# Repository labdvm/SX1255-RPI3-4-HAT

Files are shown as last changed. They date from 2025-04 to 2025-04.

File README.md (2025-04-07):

[][cc-by-nc-sa]

# SX1255_HAT-hw (schematic and pcb modified by Z32IT)
Raspberry Pi 3-4 shield with the SX1255 RF transceiver chip.

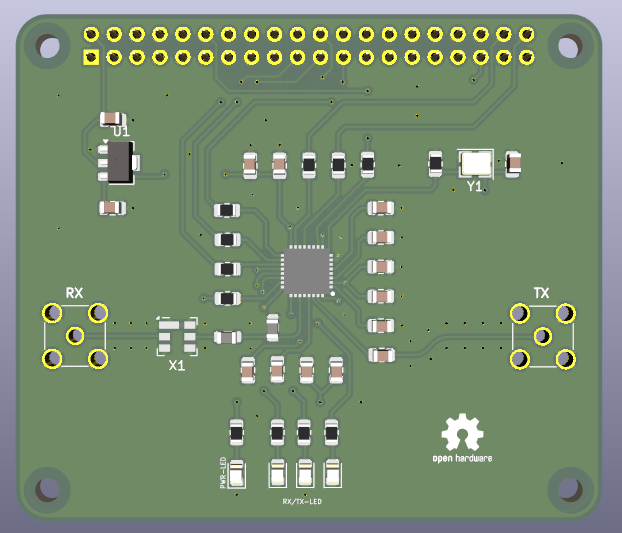
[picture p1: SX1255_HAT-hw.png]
Board preview


## Usage
### RPi sample config code
Sample Raspberry Pi code for SX1255 control can be found [here](https://gist.github.com/sp5wwp/25fa989ebd98b3b707eadae9b63af679).<br>
[I2S slave overlay](https://github.com/AkiyukiOkayasu/RaspberryPi_I2S_Slave) is required. Sample rate for both RX and TX is 125kHz.

RX/TX frequency setting:
```
./sx1255-spi 435000000 438000000
```

### Example RX with ZeroMQ
```
arecord -t raw -f S32_LE -r 192000 -c 2 --device="hw:0,1" | ./int_to_short | ./zmq-pub
```

In which `int_to_short` is a simple `int` to `short` format converter:
```C
while(1)
{
  ioctl(STDIN_FILENO, FIONREAD, &rcvd);
  if(rcvd>0)
  {
    if(read(STDIN_FILENO, inp, rcvd)==rcvd)
    {
      for(int i=0; i<rcvd; i+=8)
      {
        memcpy(&out[i/2  ], &inp[i  +2], 2);
        memcpy(&out[i/2+2], &inp[i+4+2], 2);
      }

      write(STDOUT_FILENO, out, rcvd/2);
    }
  }
}
```

### Example TX with ZeroMQ
```
./zmq-sub 192.168.50.243:17018 | aplay -t raw -f S32_LE -r 192000 -c 2 --device="hw:0,0"
```

## License
This work is licensed under a
[Creative Commons Attribution-NonCommercial-ShareAlike 4.0 International License][cc-by-nc-sa].

[][cc-by-nc-sa]

[cc-by-nc-sa]: http://creativecommons.org/licenses/by-nc-sa/4.0/
[cc-by-nc-sa-image]: https://licensebuttons.net/l/by-nc-sa/4.0/88x31.png
[cc-by-nc-sa-shield]: https://img.shields.io/badge/License-CC%20BY--NC--SA%204.0-lightgrey.svg

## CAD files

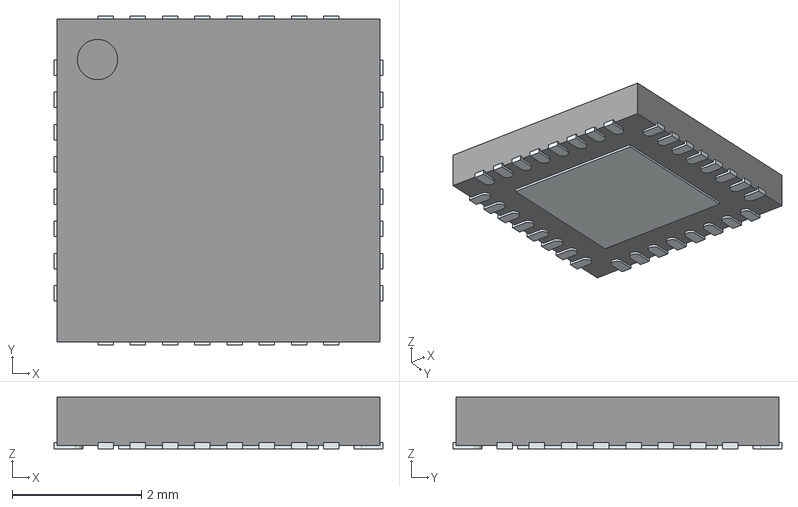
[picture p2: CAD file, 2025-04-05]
parts/SX1255IWLTRT.stp
5.10 x 5.10 x 0.8 mm
ThermalPin
PinsArrayLR
PinsArrayTB

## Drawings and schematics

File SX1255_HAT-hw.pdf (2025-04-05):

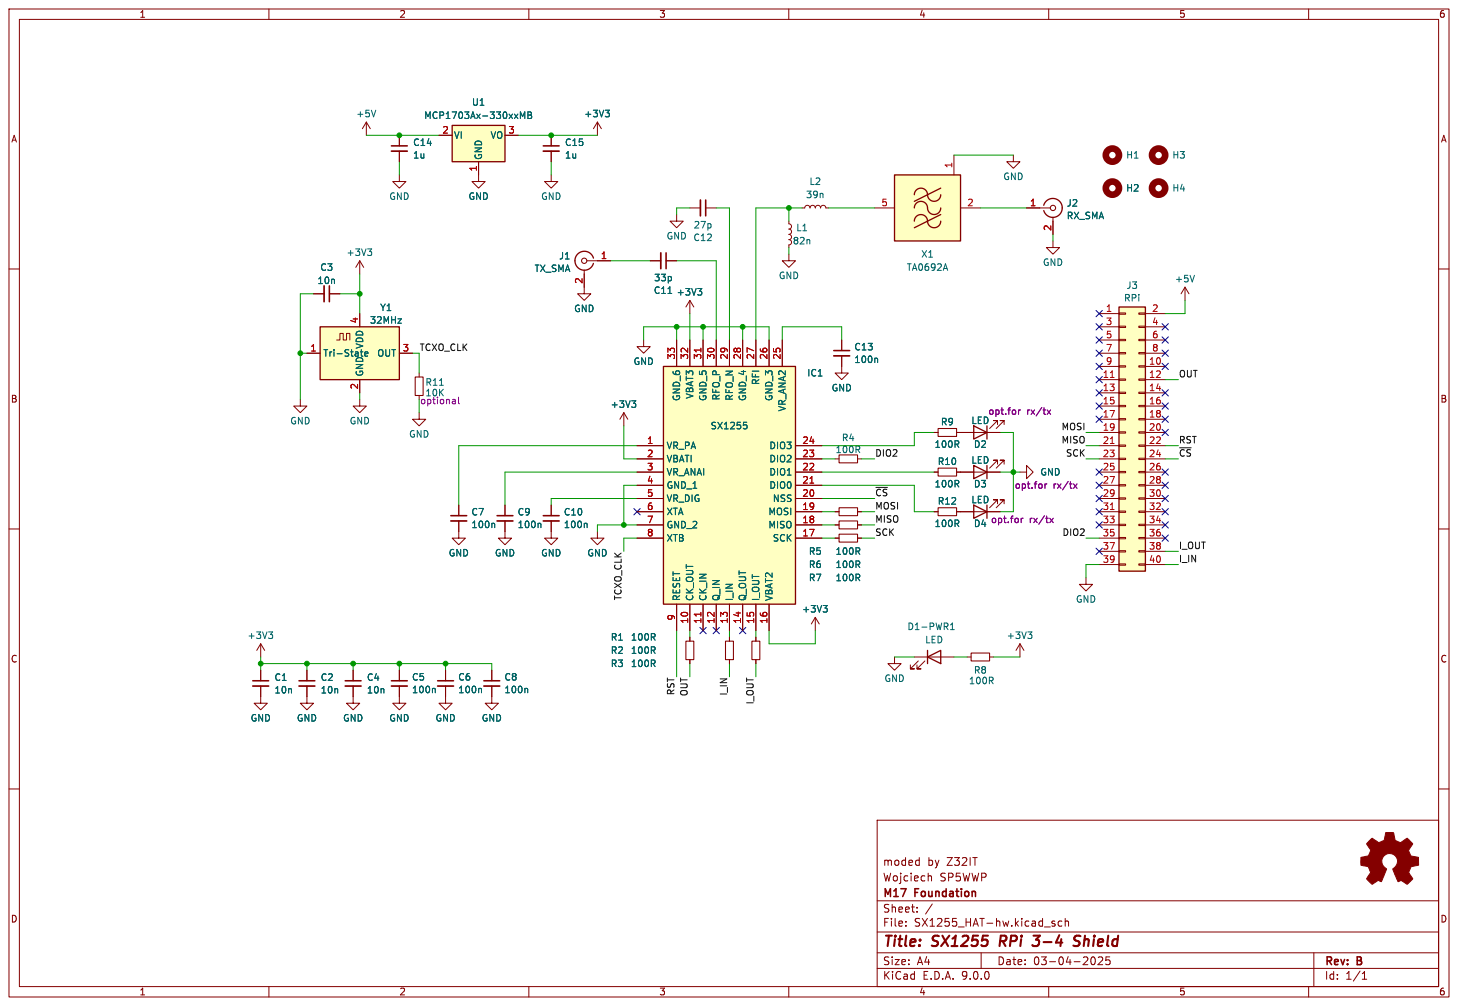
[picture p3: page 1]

27p GND
opt.for rx/tx C12

9 VBAT3 32 CK_OUT 10 GND_5 31 CK_IN 11 RFO_P 30 Q_IN 12 RFO_N 29 I_IN 13 GND_4 28 Q_OUT 14 RFI 27 I_OUT 15 GND_3 26 VBAT2 16 VR_ANA2 25 DIO3 24 DIO2 23 DIO1 22 DIO0 21 NSS 20 MOSI 19 MISO 18 SCK 17 GND

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

opt.for rx/tx R12

opt.for rx/tx D3
opt.for rx/tx D4
LED

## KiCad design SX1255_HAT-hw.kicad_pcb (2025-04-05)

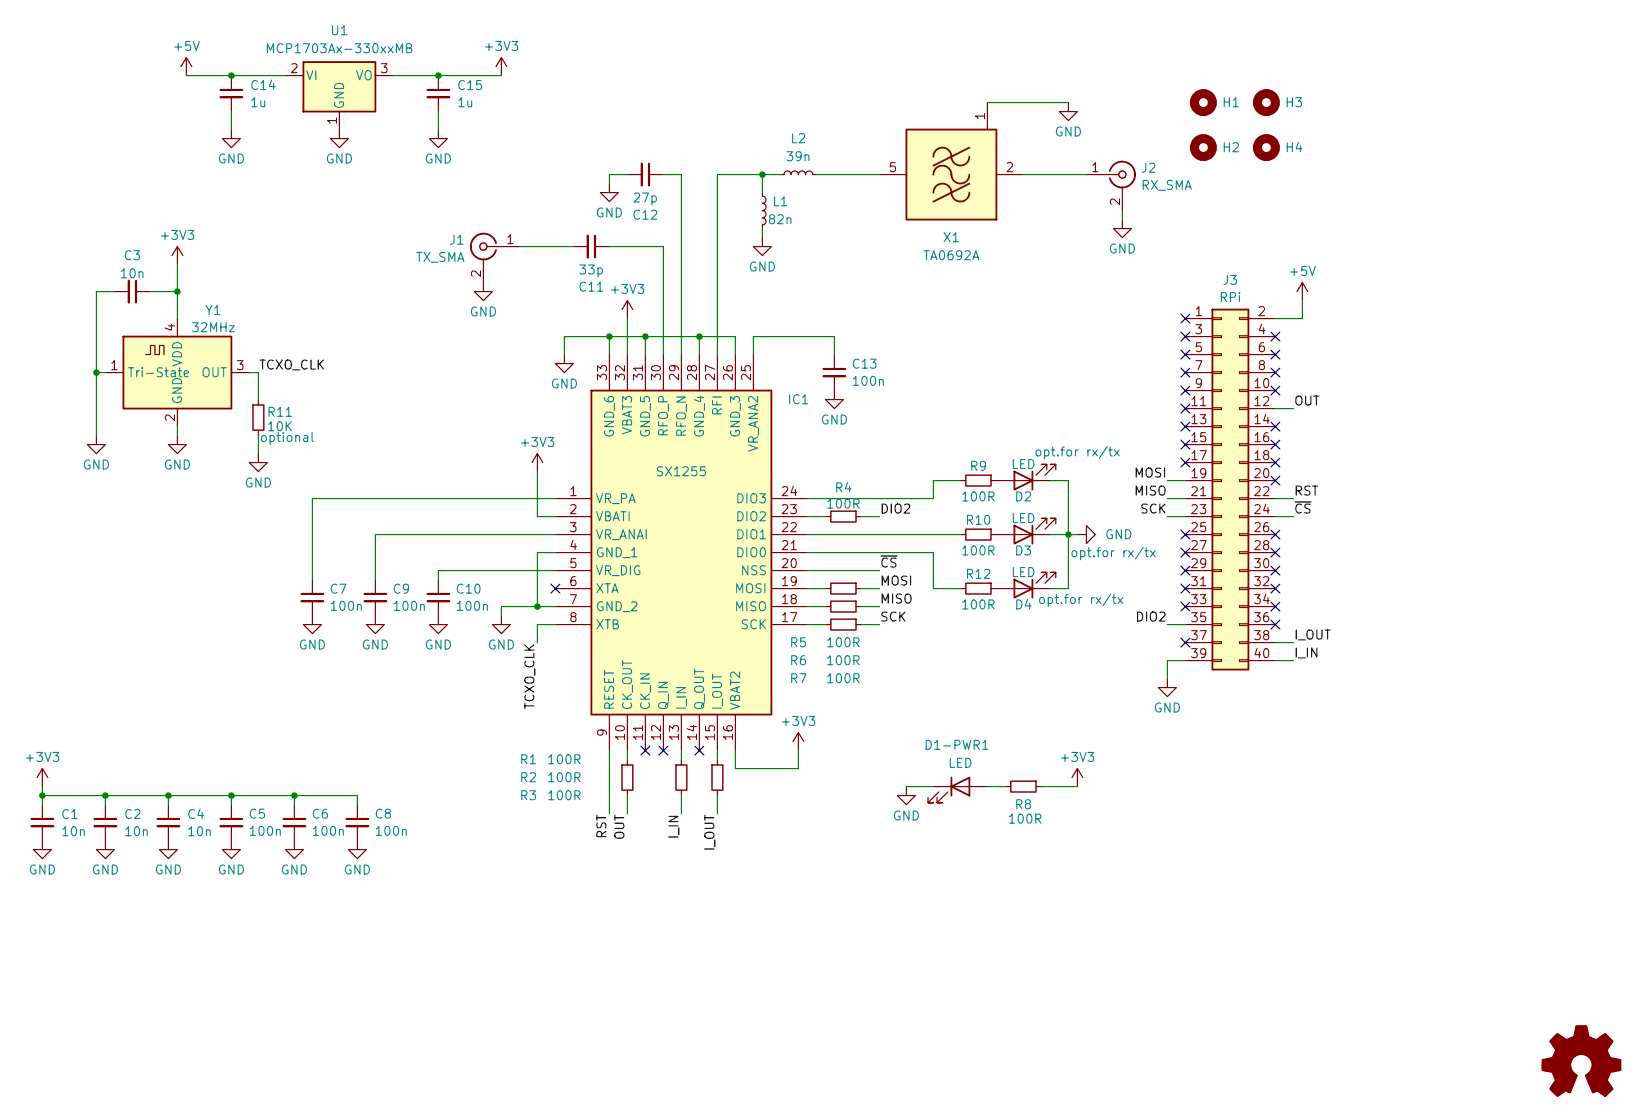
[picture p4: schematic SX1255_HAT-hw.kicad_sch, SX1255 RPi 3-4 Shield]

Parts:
C1, C2, C3, C4: 10n; C_0805_2012Metric; MPN C0603C103M4REC7411
C5, C6, C7, C8, C9, C10, C13: 100n; C_0805_2012Metric; MPN 06035G104ZAT2A
C11: 33p; C_0805_2012Metric; MPN VJ0603A330KXAPW1BC
C12: 27p; C_0805_2012Metric; MPN AC0603JRNPO9BN270
C14, C15: 1u; C_0805_2012Metric; MPN C0603C103M4REC7411
D1-PWR1, D2, D3, D4: LED; LED_0805_2012Metric
H1, H2, H3, H4: MountingHole; MountingHole_2.7mm_M2.5_DIN965
IC1: SX1255; QFN50P500X500X80-33N-D; MPN SX1255IWLTRT
J1: TX_SMA; SMA_Amphenol_901-144_Vertical; MPN RF2-04A-T-00-50-G
J2: RX_SMA; SMA_Amphenol_901-144_Vertical; MPN RF2-04A-T-00-50-G
J3: RPi; PinSocket_2x20_P2.54mm_Vertical
L1: 82n; L_0805_2012Metric; MPN AISC-0603-R082J-T
L2: 39n; L_0805_2012Metric; MPN AISC-0603-R039J-T
R1, R2, R3, R4, R5, R6, R7, R8, R9, R10, R12: 100R; R_0805_2012Metric; MPN CRCW0603100RFKECC
R11: 10K; R_0805_2012Metric; MPN CRCW0603100RFKECC
SYM1: Logo_Open_Hardware_Small; OSHW-Logo2_7.3x6mm_SilkScreen
U1: MCP1703Ax-330xxMB; SOT-89-3
X1: TA0692A; Filter_SAW-6_3.8x3.8mm
Y1: 32MHz; Crystal_SMD_3225-4Pin_3.2x2.5mm; MPN ECS-TXO-20CSMV4-320-AY-TR

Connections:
+3V3: C1.1, C2.1, C3.1, C4.1, C5.1, C6.1, C8.1, C15.1, IC1.2 (VBATI), IC1.16 (VBAT2), IC1.32 (VBAT3), R8.1, U1.3 (VO), Y1.4 (VDD)
+5V: C14.1, J3.2, U1.2 (VI)
/DIO2: J3.35, R4.1
/I_IN: J3.40, R2.2
/I_OUT: J3.38, R3.2
/MISO: J3.21, R6.1
/MOSI: J3.19, R5.1
/OUT: J3.12, R1.2
/RST: IC1.9 (RESET), J3.22
/SCK: J3.23, R7.1
/TCXO_CLK: IC1.8 (XTB), R11.1, Y1.3 (OUT)
/~CS: IC1.20 (NSS), J3.24
GND: C1.2, C2.2, C3.2, C4.2, C5.2, C6.2, C7.2, C8.2, C9.2, C10.2, C12.2, C13.2, C14.2, C15.2, D1-PWR1.1 (K), D2.1 (K), D3.1 (K), D4.1 (K), IC1.4 (GND_1), IC1.7 (GND_2), IC1.26 (GND_3), IC1.28 (GND_4), IC1.31 (GND_5), IC1.33 (GND_6), J1.2 (Ext), J2.2 (Ext), J3.39, L1.1, R11.2, U1.1 (GND), X1.1 (GND), X1.3 (GND), X1.4 (GND), X1.6 (GND), Y1.1 (Tri-State), Y1.2 (GND); also elsewhere on the board
unnamed 13: D1-PWR1.2 (A), R8.2; also elsewhere on the board
unnamed: D2.2 (A), R9.1
unnamed: D3.2 (A), R10.1
unnamed: D4.2 (A), R12.1
unnamed: IC1.10 (CK_OUT), R1.1
unnamed: IC1.21 (DIO0), R12.2
unnamed: IC1.22 (DIO1), R10.2
unnamed: IC1.23 (DIO2), R4.2
unnamed: IC1.24 (DIO3), R9.2
unnamed: IC1.13 (I_IN), R2.1
unnamed: IC1.15 (I_OUT), R3.1
unnamed: IC1.18 (MISO), R6.2
unnamed: IC1.19 (MOSI), R5.2
unnamed: IC1.27 (RFI), L1.2, L2.2
unnamed: C12.1, IC1.29 (RFO_N)
unnamed: C11.1, IC1.30 (RFO_P)
unnamed: IC1.17 (SCK), R7.2
unnamed: C13.1, IC1.25 (VR_ANA2)
unnamed: C9.1, IC1.3 (VR_ANAI)
unnamed: C10.1, IC1.5 (VR_DIG)
unnamed: C7.1, IC1.1 (VR_PA)
unnamed: C11.2, J1.1 (In)
unnamed: J2.1 (In), X1.2 (IN)
unnamed: L2.1, X1.5 (OUT)

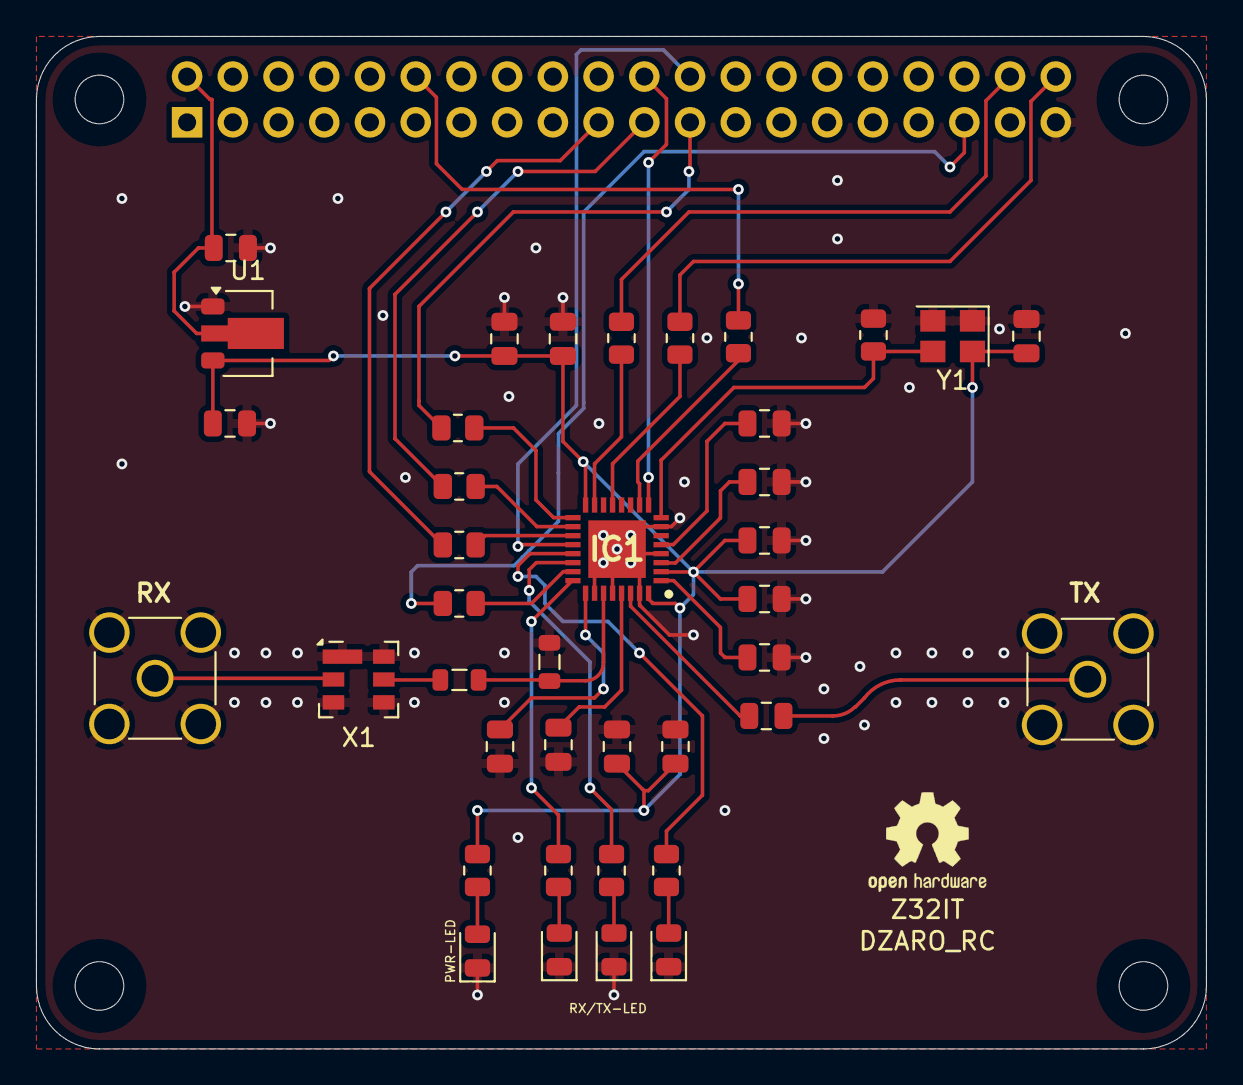
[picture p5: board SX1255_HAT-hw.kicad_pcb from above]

Board: 2 copper layers, 65.0 x 56.2 mm, 45 parts (1 on the bottom side), 37 nets.

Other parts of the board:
D1-PWR: LED; LED_0805_2012Metric

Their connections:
GND: D1-PWR.1 (K); also elsewhere on the board
unnamed 13: D1-PWR.2 (A); also elsewhere on the board

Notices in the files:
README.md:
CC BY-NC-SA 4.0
